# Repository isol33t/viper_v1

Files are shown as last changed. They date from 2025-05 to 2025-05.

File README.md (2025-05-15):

# Duck Viper v1 PCB

This repository contains KiCad files for an attempt at the Duck Viper v1 PCB design.

- Work In Progress
- Optional Split Shifts, Split Backspace, Stepped Caps Lock & ISO Enter
- No LEDs
- With 5 rows and 14 columns, there is only 1 pin left on the Atmega

## Files Included
- KiCad project files
- Schematic
- PCB layout

## Usage
Open the project in KiCad to view and modify the design.

## Revision 5.2025
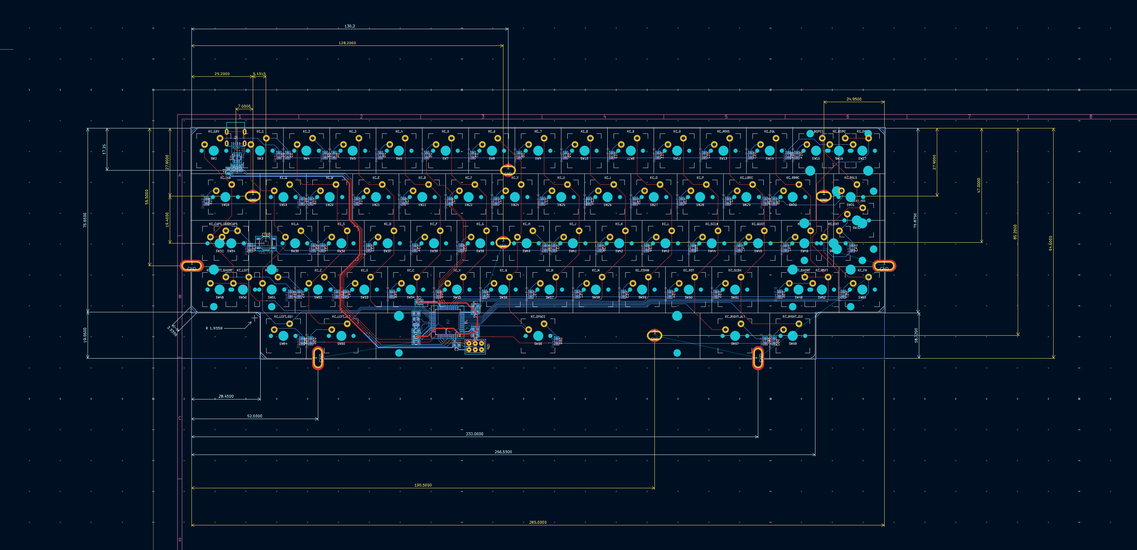
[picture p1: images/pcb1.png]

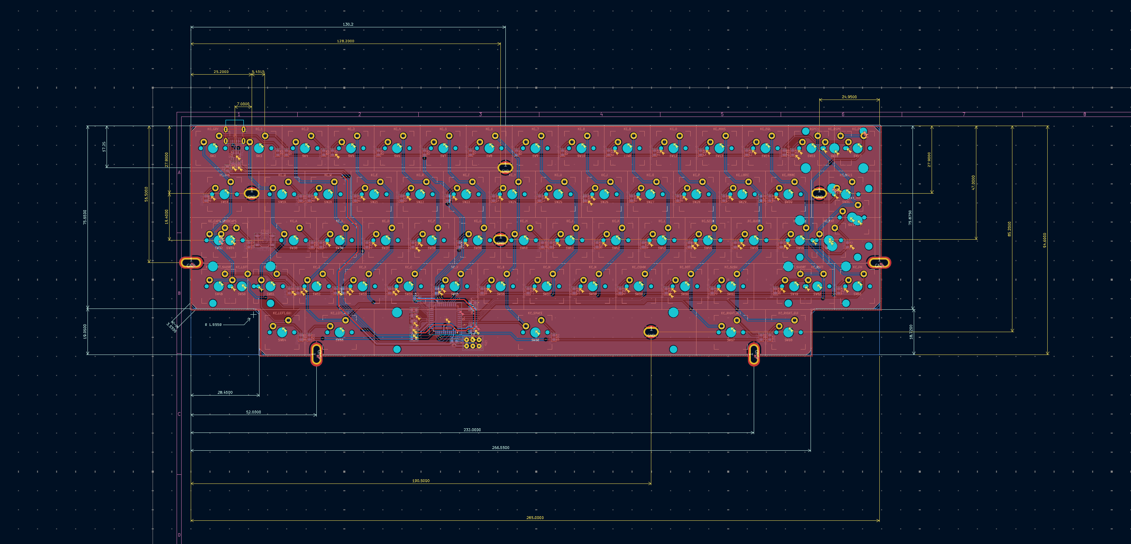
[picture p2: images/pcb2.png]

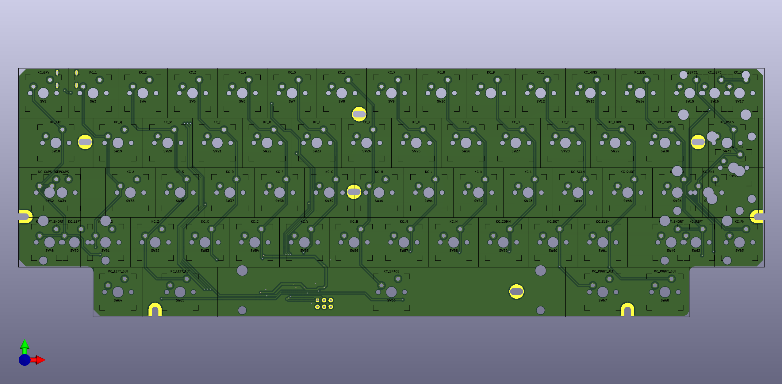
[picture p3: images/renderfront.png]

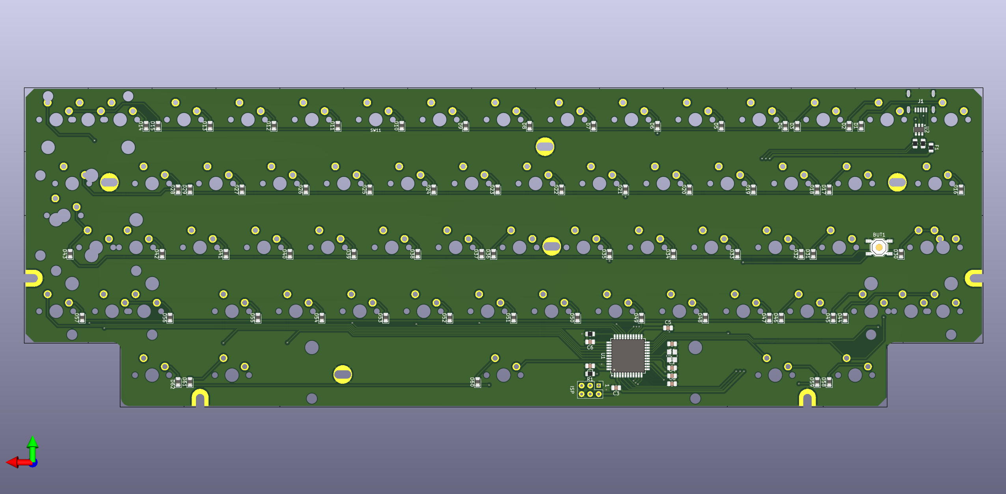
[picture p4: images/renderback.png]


## Thanks yo
- https://github.com/ruiqimao/keyboard-pcb-guide
- https://wiki.ai03.com/books/pcb-design
- https://github.com/evyd13/plain60-b
- https://github.com/evyd13/plain60-c
- https://www.masterzen.fr/2020/05/03/designing-a-keyboard-part-1/
- https://imgur.com/LQXco3J

## Todo
- Leds?
- https://github.com/adamws/keyboard-tools
- https://keyboard-tools.xyz

## Notes
- Is the reset switch position correct?
- [Japanese duplex matrix](https://kbd.news/The-Japanese-duplex-matrix-1391.html)
- [Pulldown resistor on KMAC Happy](https://geekhack.org/index.php?topic=87703.msg2485259#msg2485259)
- [Nexperia 74HC237 3-to-8 line decoder, demultiplexer with address latches](https://assets.nexperia.com/documents/data-sheet/74HC237.pdf)
- [hasu re: 74HC238](https://geekhack.org/index.php?topic=35065.msg966423#msg966423)

## License
MIT License

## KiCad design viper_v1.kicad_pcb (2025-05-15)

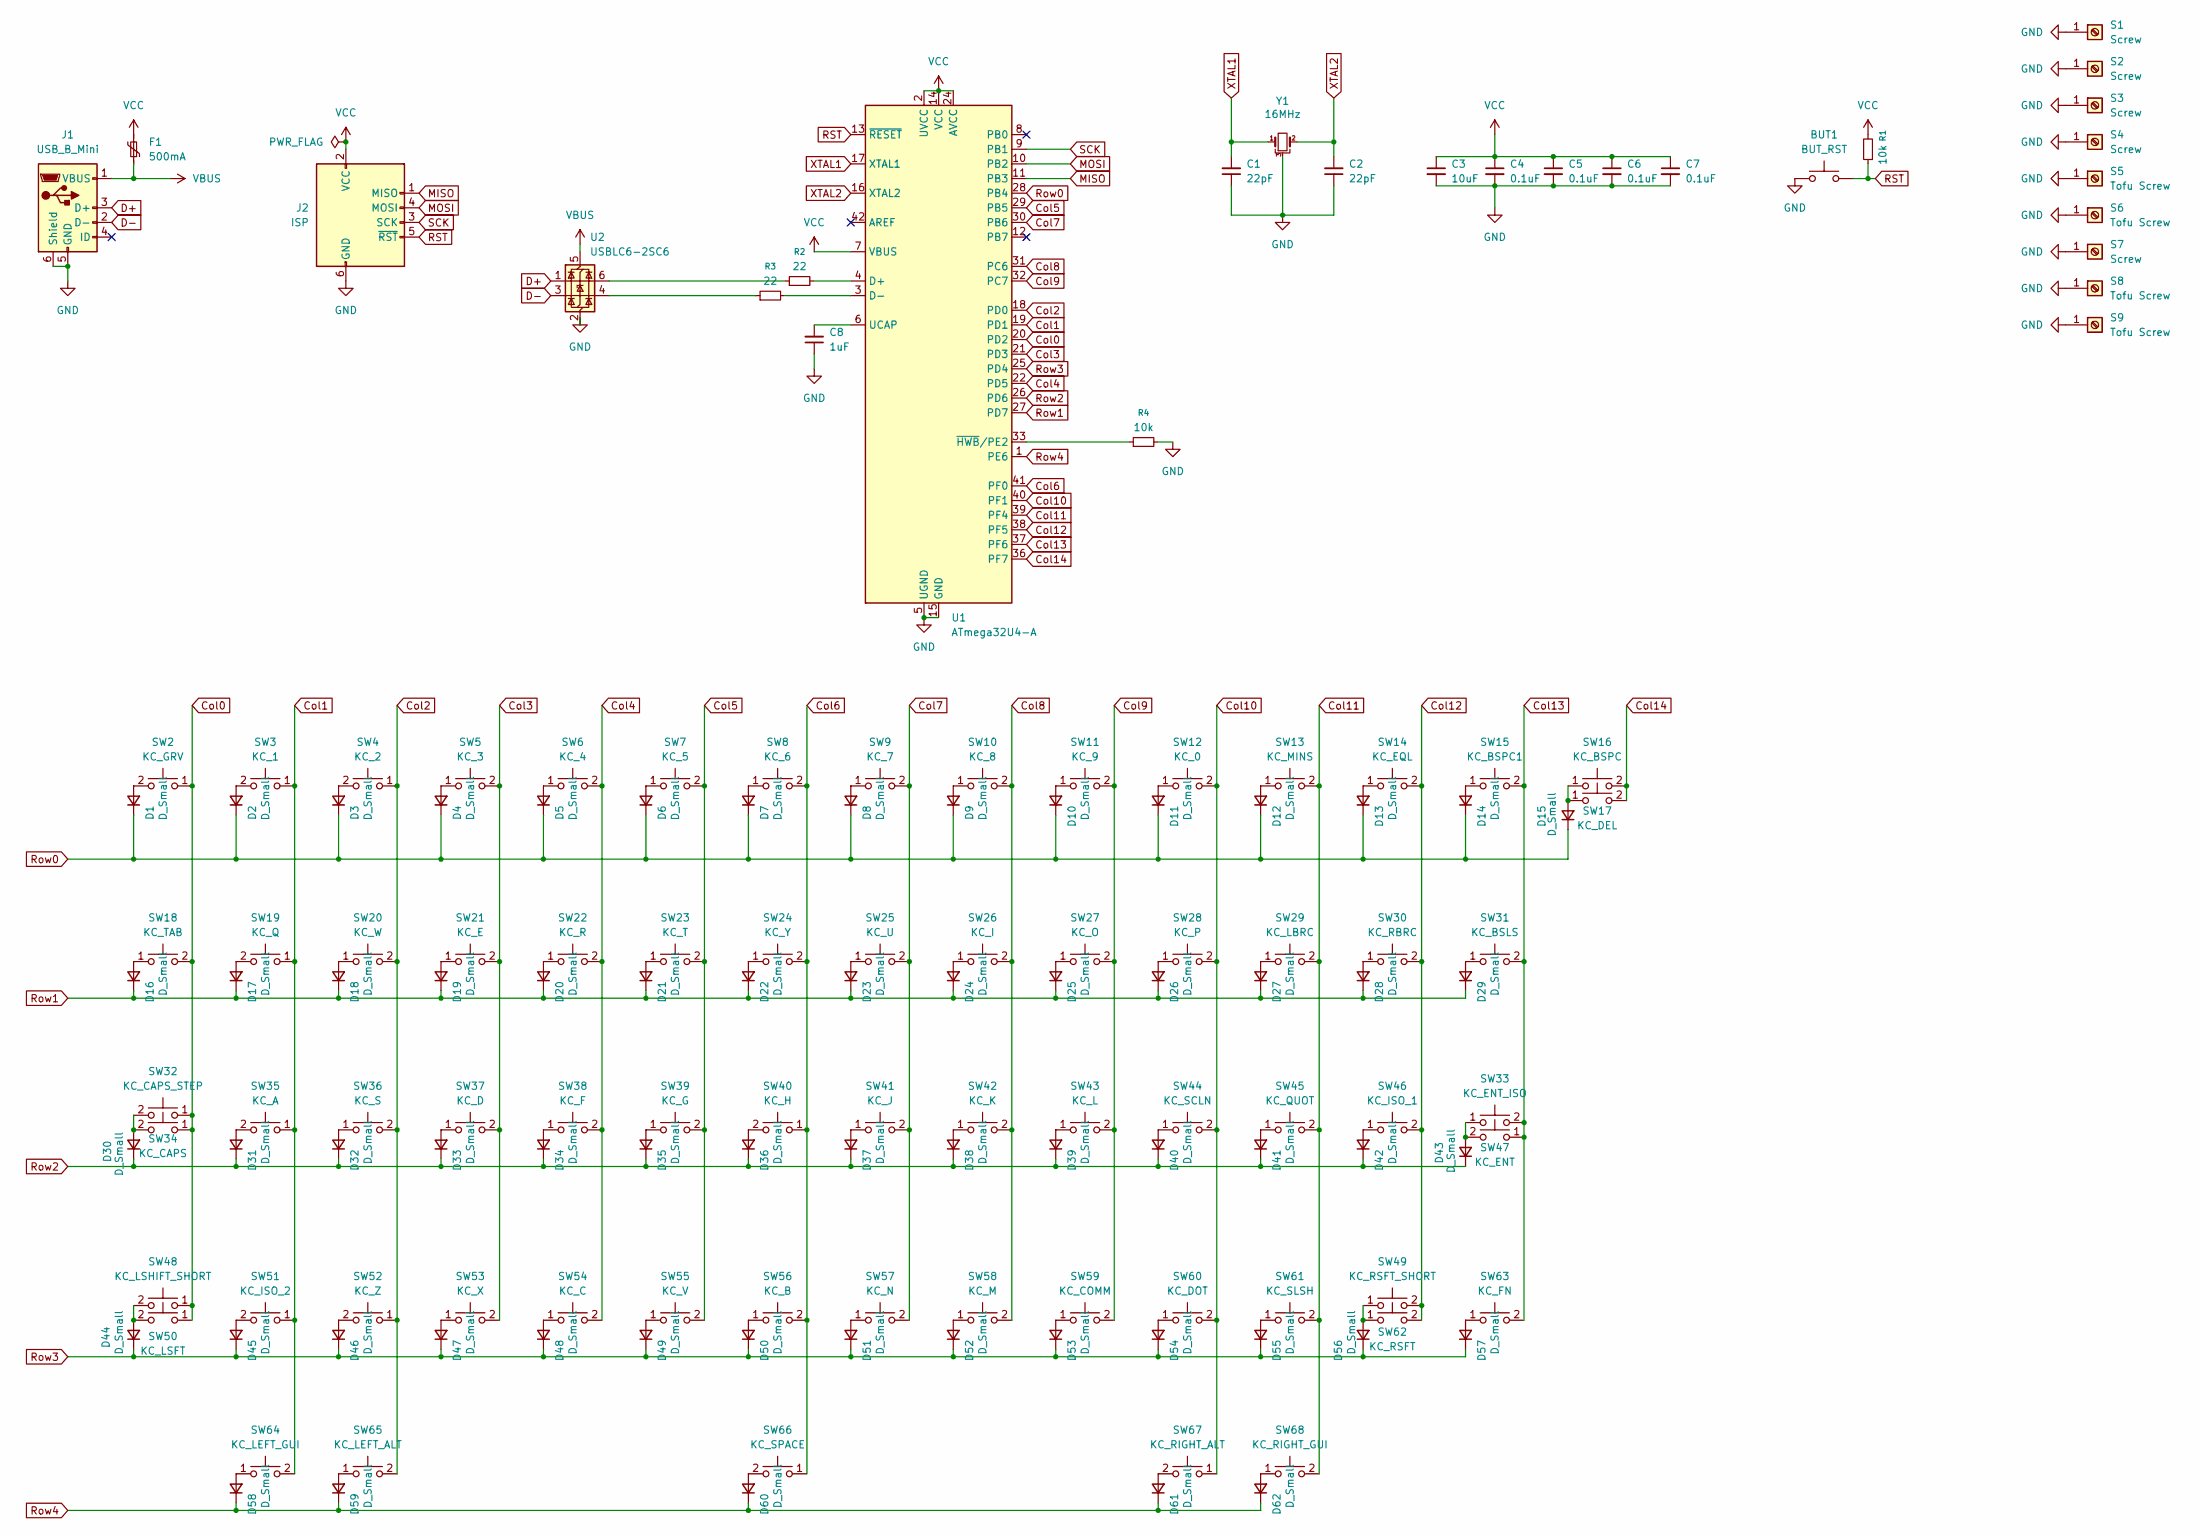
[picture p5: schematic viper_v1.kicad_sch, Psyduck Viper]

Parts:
BUT1: BUT_RST; SW_SPST_TL3342
C1, C2: 22pF; C_0805_2012Metric
C3: 10uF; C_0805_2012Metric
C4, C5, C6, C7: 0.1uF; C_0805_2012Metric
C8: 1uF; C_0805_2012Metric
D1, D2, D3, D4, D5, D6, D7, D8, D9, D10, D11, D12, D13, D14, D15, D16, D17, D18, D19, D20, D21, D22, D23, D24, D25, D26, D27, D28, D29, D30, D31, D32, D33, D34, D35, D36, D37, D38, D39, D40, D41, D42, D43, D44, D45, D46, D47, D48, D49, D50, D51, D52, D53, D54, D55, D56, D57, D58, D59, D60, D61, D62: D_Small; D_0805_2012Metric
F1: 500mA; Fuse_0805_2012Metric
J1: USB_B_Mini; HRO-U-M-M5DD-W-1
J2: ISP; isp_standard
R1, R4: 10k; R_0805_2012Metric
R2, R3: 22; R_0805_2012Metric
S1, S2, S3, S4, S7: Screw; 5.5_5x2.5mm
S5, S6, S8, S9: Tofu Screw; 10x5_7x2.5mm
SW2: KC_GRV; MX-Solderable-1U
SW3: KC_1; MX-Solderable-1U
SW4: KC_2; MX-Solderable-1U
SW5: KC_3; MX-Solderable-1U
SW6: KC_4; MX-Solderable-1U
SW7: KC_5; MX-Solderable-1U
SW8: KC_6; MX-Solderable-1U
SW9: KC_7; MX-Solderable-1U
SW10: KC_8; MX-Solderable-1U
SW11: KC_9; MX-Solderable-1U
SW12: KC_0; MX-Solderable-1U
SW13: KC_MINS; MX-Solderable-1U
SW14: KC_EQL; MX-Solderable-1U
SW15: KC_BSPC1; MX-Solderable-1U
SW16: KC_BSPC; MX-Solderable-2U
SW17: KC_DEL; MX-Solderable-1U
SW18: KC_TAB; MX-Solderable-1.5U
SW19: KC_Q; MX-Solderable-1U
SW20: KC_W; MX-Solderable-1U
SW21: KC_E; MX-Solderable-1U
SW22: KC_R; MX-Solderable-1U
SW23: KC_T; MX-Solderable-1U
SW24: KC_Y; MX-Solderable-1U
SW25: KC_U; MX-Solderable-1U
SW26: KC_I; MX-Solderable-1U
SW27: KC_O; MX-Solderable-1U
SW28: KC_P; MX-Solderable-1U
SW29: KC_LBRC; MX-Solderable-1U
SW30: KC_RBRC; MX-Solderable-1U
SW31: KC_BSLS; MX-Solderable-1.5U
SW32: KC_CAPS_STEP; MX-Solderable-1.25U
SW33: KC_ENT_ISO; MX-Solderable-2U-Vertical
SW34: KC_CAPS; MX-Solderable-1.75U
SW35: KC_A; MX-Solderable-1U
SW36: KC_S; MX-Solderable-1U
SW37: KC_D; MX-Solderable-1U
SW38: KC_F; MX-Solderable-1U
SW39: KC_G; MX-Solderable-1U
SW40: KC_H; MX-Solderable-1U
SW41: KC_J; MX-Solderable-1U
SW42: KC_K; MX-Solderable-1U
SW43: KC_L; MX-Solderable-1U
SW44: KC_SCLN; MX-Solderable-1U
SW45: KC_QUOT; MX-Solderable-1U
SW46: KC_ISO_1; MX-Solderable-1U
SW47: KC_ENT; MX-Solderable-2.25U-ReversedStabilizers
SW48: KC_LSHIFT_SHORT; MX-Solderable-1.25U
SW49: KC_RSFT_SHORT; MX-Solderable-1.75U
SW50: KC_LSFT; MX-Solderable-2.25U-ReversedStabilizers
SW51: KC_ISO_2; MX-Solderable-1U
SW52: KC_Z; MX-Solderable-1U
SW53: KC_X; MX-Solderable-1U
SW54: KC_C; MX-Solderable-1U
SW55: KC_V; MX-Solderable-1U
SW56: KC_B; MX-Solderable-1U
SW57: KC_N; MX-Solderable-1U
SW58: KC_M; MX-Solderable-1U
SW59: KC_COMM; MX-Solderable-1U
SW60: KC_DOT; MX-Solderable-1U
SW61: KC_SLSH; MX-Solderable-1U
SW62: KC_RSFT; MX-Solderable-2.75U-ReversedStabilizers
SW63: KC_FN; MX-Solderable-1U
SW64: KC_LEFT_GUI; MX-Solderable-1U
SW65: KC_LEFT_ALT; MX-Solderable-1.5U
SW66: KC_SPACE; MX-Solderable-7U-ReversedStabilizers
SW67: KC_RIGHT_ALT; MX-Solderable-1.5U
SW68: KC_RIGHT_GUI; MX-Solderable-1U
U1: ATmega32U4-A; TQFP-44_10x10mm_P0.8mm
U2: USBLC6-2SC6; SOT-23-6
Y1: 16MHz; crystal_FA238-TSX3225

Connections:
Col0: SW2.1, SW18.2, SW32.1, SW34.1, SW48.1, SW50.1, U1.20 (PD2)
Col1: SW3.1, SW19.1, SW35.1, SW51.1, SW64.2, U1.19 (PD1)
Col2: SW4.1, SW20.2, SW36.2, SW52.1, SW65.2, U1.18 (PD0)
Col3: SW5.2, SW21.2, SW37.2, SW53.2, U1.21 (PD3)
Col4: SW6.2, SW22.2, SW38.2, SW54.2, U1.22 (PD5)
Col5: SW7.2, SW23.2, SW39.2, SW55.2, U1.29 (PB5)
Col6: SW8.2, SW24.2, SW40.1, SW56.2, SW66.1, U1.41 (PF0)
Col7: SW9.2, SW25.2, SW41.2, SW57.2, U1.30 (PB6)
Col8: SW10.2, SW26.2, SW42.2, SW58.2, U1.31 (PC6)
Col9: SW11.2, SW27.2, SW43.2, SW59.2, U1.32 (PC7)
Col10: SW12.2, SW28.2, SW44.2, SW60.2, SW67.1, U1.40 (PF1)
Col11: SW13.2, SW29.2, SW45.2, SW61.2, SW68.2, U1.39 (PF4)
Col12: SW14.2, SW30.2, SW46.2, SW49.2, SW62.2, U1.38 (PF5)
Col13: SW15.2, SW31.2, SW33.2, SW47.1, SW63.2, U1.37 (PF6)
Col14: SW16.2, SW17.2, U1.36 (PF7)
D+: J1.3 (D+), U2.1 (I/O1)
D-: J1.2 (D-), U2.3 (I/O2)
GND: BUT1.1, C1.1, C2.1, C3.2, C4.2, C5.2, C6.2, C7.2, C8.1, J1.5 (GND), J1.6 (Shield), J2.6 (GND), R4.2, S1.1, S2.1, S3.1, S4.1, S5.1, S6.1, S7.1, S8.1, S9.1, U1.5 (UGND), U1.15 (GND), U1.23 (GND), U1.35 (GND), U1.43 (GND), U2.2 (GND), Y1.3
MISO: J2.1 (MISO), U1.11 (PB3)
MOSI: J2.4 (MOSI), U1.10 (PB2)
unnamed: D1.2 (A), SW2.2
unnamed: D2.2 (A), SW3.2
unnamed: D3.2 (A), SW4.2
unnamed: D4.2 (A), SW5.1
unnamed: D5.2 (A), SW6.1
unnamed: D6.2 (A), SW7.1
unnamed: D7.2 (A), SW8.1
unnamed: D8.2 (A), SW9.1
unnamed: D9.2 (A), SW10.1
unnamed: D10.2 (A), SW11.1
unnamed: D11.2 (A), SW12.1
unnamed: D12.2 (A), SW13.1
unnamed: D13.2 (A), SW14.1
unnamed: D14.2 (A), SW15.1
unnamed: D15.2 (A), SW16.1, SW17.1
unnamed: D16.2 (A), SW18.1
unnamed: D17.2 (A), SW19.2
unnamed: D18.2 (A), SW20.1
unnamed: D19.2 (A), SW21.1
unnamed: D20.2 (A), SW22.1
unnamed: D21.2 (A), SW23.1
unnamed: D22.2 (A), SW24.1
unnamed: D23.2 (A), SW25.1
unnamed: D24.2 (A), SW26.1
unnamed: D25.2 (A), SW27.1
unnamed: D26.2 (A), SW28.1
unnamed: D27.2 (A), SW29.1
unnamed: D28.2 (A), SW30.1
unnamed: D29.2 (A), SW31.1
unnamed: D30.2 (A), SW32.2, SW34.2
unnamed: D31.2 (A), SW35.2
unnamed: D32.2 (A), SW36.1
unnamed: D33.2 (A), SW37.1
unnamed: D34.2 (A), SW38.1
unnamed: D35.2 (A), SW39.1
unnamed: D36.2 (A), SW40.2
unnamed: D37.2 (A), SW41.1
unnamed: D38.2 (A), SW42.1
unnamed: D39.2 (A), SW43.1
unnamed: D40.2 (A), SW44.1
unnamed: D41.2 (A), SW45.1
unnamed: D42.2 (A), SW46.1
unnamed: D43.2 (A), SW33.1, SW47.2
unnamed: D44.2 (A), SW48.2, SW50.2
unnamed: D45.2 (A), SW51.2
unnamed: D46.2 (A), SW52.2
unnamed: D47.2 (A), SW53.1
unnamed: D48.2 (A), SW54.1
unnamed: D49.2 (A), SW55.1
unnamed: D50.2 (A), SW56.1
unnamed: D51.2 (A), SW57.1
unnamed: D52.2 (A), SW58.1
unnamed: D53.2 (A), SW59.1
unnamed: D54.2 (A), SW60.1
unnamed: D55.2 (A), SW61.1
unnamed: D56.2 (A), SW49.1, SW62.1
unnamed: D57.2 (A), SW63.1
unnamed: D58.2 (A), SW64.1
unnamed: D59.2 (A), SW65.1
unnamed: D60.2 (A), SW66.2
unnamed: D61.2 (A), SW67.2
unnamed: D62.2 (A), SW68.1
unnamed: R2.1, U2.6 (I/O1)
unnamed: R3.1, U2.4 (I/O2)
unnamed: R2.2, U1.4 (D+)
unnamed: R3.2, U1.3 (D-)
unnamed: C8.2, U1.6 (UCAP)
unnamed: R4.1, U1.33 (~HWB/PE2)
RST: BUT1.2, J2.5 (~RST), R1.1, U1.13 (~RESET)
Row0: D1.1 (K), D2.1 (K), D3.1 (K), D4.1 (K), D5.1 (K), D6.1 (K), D7.1 (K), D8.1 (K), D9.1 (K), D10.1 (K), D11.1 (K), D12.1 (K), D13.1 (K), D14.1 (K), D15.1 (K), U1.28 (PB4)
Row1: D16.1 (K), D17.1 (K), D18.1 (K), D19.1 (K), D20.1 (K), D21.1 (K), D22.1 (K), D23.1 (K), D24.1 (K), D25.1 (K), D26.1 (K), D27.1 (K), D28.1 (K), D29.1 (K), U1.27 (PD7)
Row2: D30.1 (K), D31.1 (K), D32.1 (K), D33.1 (K), D34.1 (K), D35.1 (K), D36.1 (K), D37.1 (K), D38.1 (K), D39.1 (K), D40.1 (K), D41.1 (K), D42.1 (K), D43.1 (K), U1.26 (PD6)
Row3: D44.1 (K), D45.1 (K), D46.1 (K), D47.1 (K), D48.1 (K), D49.1 (K), D50.1 (K), D51.1 (K), D52.1 (K), D53.1 (K), D54.1 (K), D55.1 (K), D56.1 (K), D57.1 (K), U1.25 (PD4)
Row4: D58.1 (K), D59.1 (K), D60.1 (K), D61.1 (K), D62.1 (K), U1.1 (PE6)
SCK: J2.3 (SCK), U1.9 (PB1)
VBUS: F1.1, J1.1 (VBUS), U2.5 (VBUS)
VCC: C3.1, C4.1, C5.1, C6.1, C7.1, F1.2, J2.2 (VCC), R1.2, U1.2 (UVCC), U1.7 (VBUS), U1.14 (VCC), U1.24 (AVCC), U1.34 (VCC), U1.44 (AVCC)
XTAL1: C1.2, U1.17 (XTAL1), Y1.1
XTAL2: C2.2, U1.16 (XTAL2), Y1.2

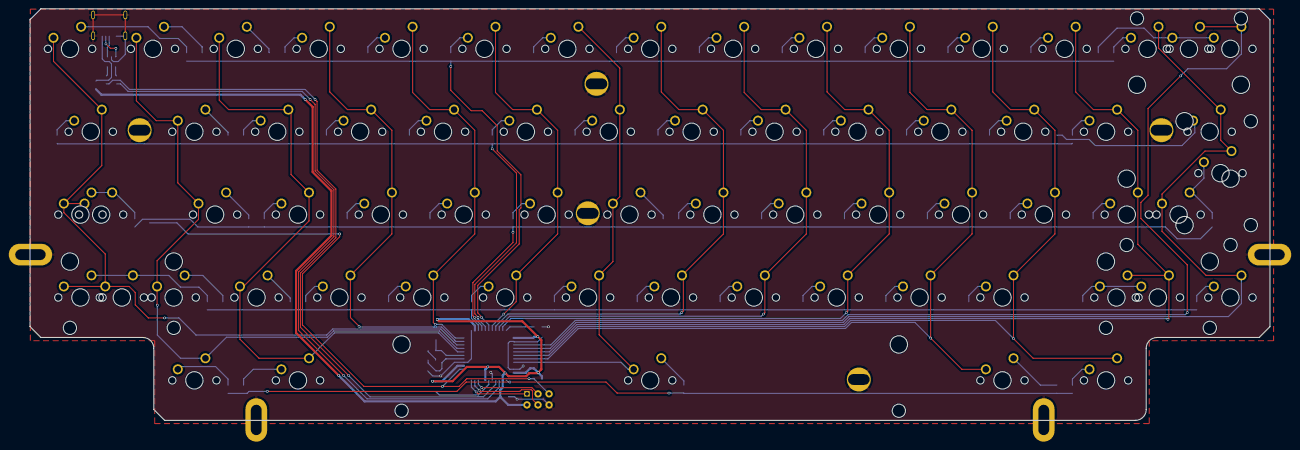
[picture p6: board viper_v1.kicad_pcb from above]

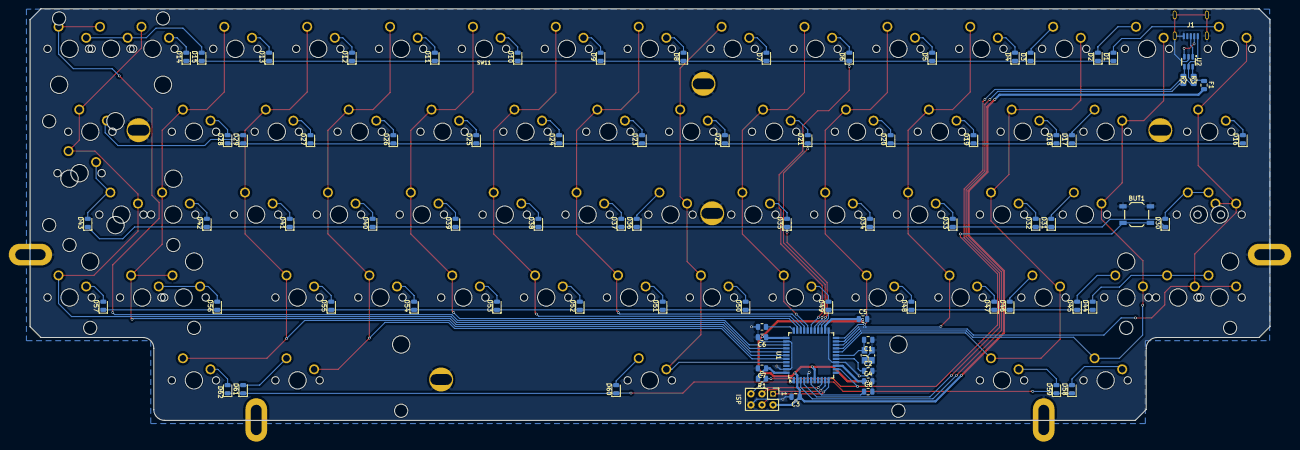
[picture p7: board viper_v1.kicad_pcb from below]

Board: 2 copper layers, 285.0 x 94.6 mm, 157 parts (81 on the bottom side), 99 nets.

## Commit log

2025-05-05 Add jlcpcb production file with gerbers from rev1 and scans.
2025-05-15 Cleanup of old half-baked attempt
    Fresh start
    Included ai03 random-keyboard-parts submodule & set up libs in kicad.
    Add first rows/columns
    [Viper.kicad_pcb, Viper.sch, Viper_2025.kicad_pcb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]
2025-05-15 Assigned footprints
    Updated/reannotated schematic
    init pcb with viper outline
    Add ISP header
    [viper_v1.kicad_pcb, viper_v1.kicad_sch]
2025-05-15 Added rows/columns for simple wkl layout
    Added values to keys in schematic & updated meta keys
    Aligned switches & diodes
    Moved some footprints around to prevent overlapping.
    Added PWR Flags & connected shield
    Custom SKQG footprint.
    Set up 15mil power netclass for +5V, VCC & GND
    [viper_v1.kicad_pcb, viper_v1.kicad_sch]
2025-05-15 Moved footprints to 0,0
    Added better mounting holes
    Testing different usb miniB footprints & replaced mounting holes.
    Added another decoupling cap.
    Reannotated parts
    Centered diodes under switches where possible
    Changed PCB edges around USB connector & added (optional) rounded corners.
    45deg corners
    Swapped rows/columns
    Adding additional switch footprints.
    [viper_v1.kicad_pcb, viper_v1.kicad_sch]
2025-05-15 Placed new footprints for iso enter, short shifts, stepped caps, fn & 2 more iso switches.
    Added USBLC6-2SC6 for ESD protection
    [viper_v1.kicad_pcb, viper_v1.kicad_sch]
2025-05-15 Fixed broken cols for stacked keys & added HRO-U-M-M5DD-W-1.kicad_mod from mymakercorner/Phoenix_Project_No1
    Set wider track width for power & default.
    Moved parts around usb connector around
    Started wiring usb.
    Added GND zones
    [viper_v1.kicad_pcb, viper_v1.kicad_sch]
2025-05-15 Swapped ISP header & xtal footprint & connected all ratsnests
    aligned vias
    Renamed some screws & removed net labels
    [viper_v1.kicad_pcb, viper_v1.kicad_sch]
2025-05-15 Included viper v1 pcb dimensions
    [viper_v1.kicad_pcb]
2025-05-15 Fixed bottom pcb outline
    [viper_v1.kicad_pcb]
2025-05-15 Added default 60 measurements on user comment 4, viper measurements on user comment 3
    Moved all parts from 0,0 to 25,25
    [viper_v1.kicad_pcb]
2025-05-15 Also moved zones to 25,25.
    [viper_v1.kicad_pcb]
2025-05-15 Created simple footprint of viper v1 edge cuts.
